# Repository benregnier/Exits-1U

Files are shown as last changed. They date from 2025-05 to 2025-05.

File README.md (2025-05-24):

# Exits
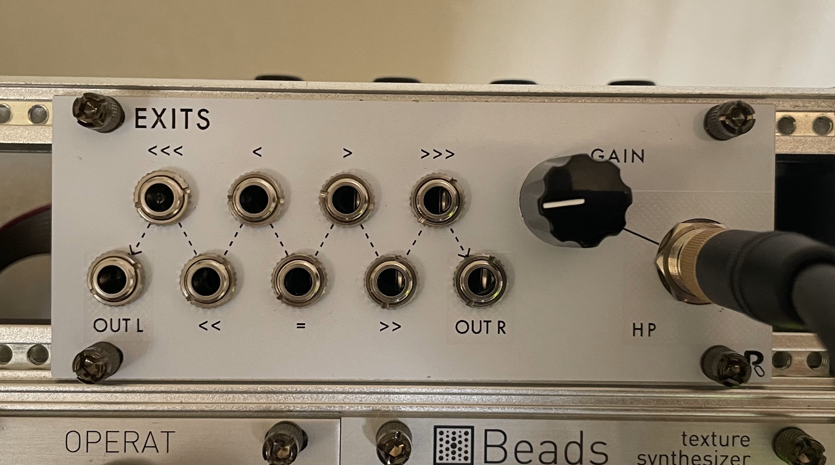
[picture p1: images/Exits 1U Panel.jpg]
exits


4hp DIY eurorack line and headphone output module based on [Exits](https://github.com/ramphands/Exits) which is in part based on [Nearness](https://github.com/sarnesjo/nearness) and [Forestcaver headphone amp](https://github.com/forestcaver/Analog-Voice/tree/master/AJH_Headphone_Amp) designs. 

The Nearness section is a "minimal panning mixer for the Eurorack modular synthesizer system. Seven inputs, two outputs. The closer an input is to an output, the greater its influence on it."  

This design makes the following changes:
- Changed to a 1U format
- Reestablishes front panel L and R outputs
- In lieu of a stereo 1/4 main out, has a six-pin connector that is compatible with Intellijel cases.
- NE5532 in lieu of NJM4556 for the headphone portion

## Schematic and PCBs

The [kicad](Kicad) directory contains the schematic and PCB layout as a KiCad 6 project.

## Panel

Available in the [panel](Panel) directory as a PDF and an SVG vector file as well as PCB design and gerbers.

## Intellijel Output Pinout

This module has a six pin connector on the back meant to be compatible with outputs on Intellijel and Befaco cases. Pinouts match per the diagram below. Outputs are not balanced.  Note that if you want to mount this module on the far right hand side of the case both the output and power ribbon cables need to be low-profile.  

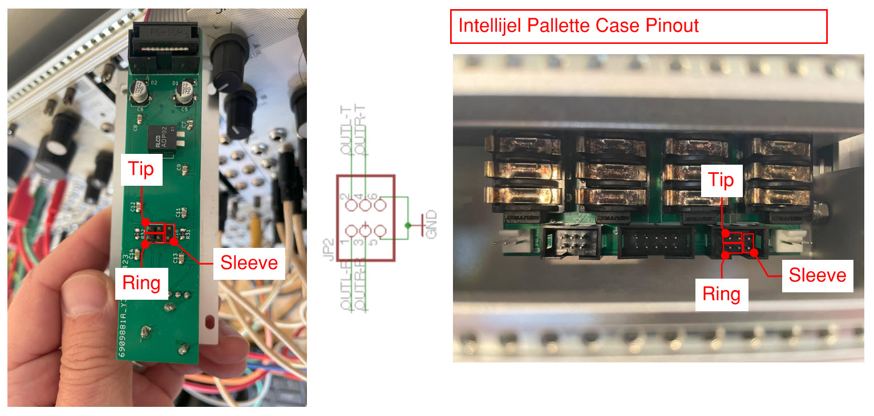
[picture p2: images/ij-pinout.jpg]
pinout


## License

[CC BY-SA 4.0](http://creativecommons.org/licenses/by-sa/4.0/)

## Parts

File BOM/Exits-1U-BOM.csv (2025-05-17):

Id | Designator | Footprint | Quantity | Designation | Supplier and ref
1 | IC2,IC1 | SOIC-8_3.9x4.9mm_P1.27mm | 2 | NE5532
2 | J2,J13,J1,J15,J6,J3,J4,J5,J7 | PJ301M12 | 9 | PJ301M12
3 | U4,U3 | SOIC-8_3.9x4.9mm_P1.27mm | 2 | LME49720
4 | R17,R27,R28,R19,R15,R16,R20,R21,R18,R22,R1,R14 | R_0805_2012Metric_Pad1.20x1.40mm_HandSolder | 12 | 100k
5 | RV1 | Potentiometer_Alpha_RD902F-40-00D_Dual_Vertical | 1 | 50k A
6 | C4,C3 | C_0805_2012Metric_Pad1.18x1.45mm_HandSolder | 2 | 22p
7 | R23,R25,R26,R24 | R_0805_2012Metric_Pad1.20x1.40mm_HandSolder | 4 | 1
8 | J14 | CUI_SJ-63083A | 1 | SJ-63083A
9 | R30,R29,R31,R32 | R_0805_2012Metric_Pad1.20x1.40mm_HandSolder | 4 | 1k
10 | C2,C1,C8,C14,C13,C9,C12,C10,C7,C11 | C_0805_2012Metric_Pad1.18x1.45mm_HandSolder | 10 | 100n
11 | J8 | PinHeader_1x04_P2.54mm_Vertical | 1 | Conn_01x04_Male
12 | J11 | PinHeader_1x06_P2.54mm_Vertical | 1 | Conn_01x06_Male
13 | C6,C5 | C_Elec_5x5.8 | 2 | 22u
14 | R9,R6 | R_0805_2012Metric_Pad1.20x1.40mm_HandSolder | 2 | 215k
15 | J10 | PinSocket_1x06_P2.54mm_Vertical | 1 | Conn_01x06_Female
16 | J16 | PinHeader_2x03_P2.54mm_Vertical | 1 | Conn_02x03_Odd_Even
17 | J12 | IDC-Header_2x05_P2.54mm_Vertical | 1 | Euro power header
18 | R8,R7 | R_0805_2012Metric_Pad1.20x1.40mm_HandSolder | 2 | 140k
19 | S1 | ADP0204 | 1 | ADP0204
20 | R10,R5 | R_0805_2012Metric_Pad1.20x1.40mm_HandSolder | 2 | 113k
21 | D1,D2 | D_SOD-123 | 2 | 1N5819HW
22 | J9 | PinSocket_1x04_P2.54mm_Vertical | 1 | Conn_01x04_Female
23 | R11,R4 | R_0805_2012Metric_Pad1.20x1.40mm_HandSolder | 2 | 442k
24 | R13,R2 | R_0805_2012Metric_Pad1.20x1.40mm_HandSolder | 2 | 1M69
25 | R12,R3 | R_0805_2012Metric_Pad1.20x1.40mm_HandSolder | 2 | 102k

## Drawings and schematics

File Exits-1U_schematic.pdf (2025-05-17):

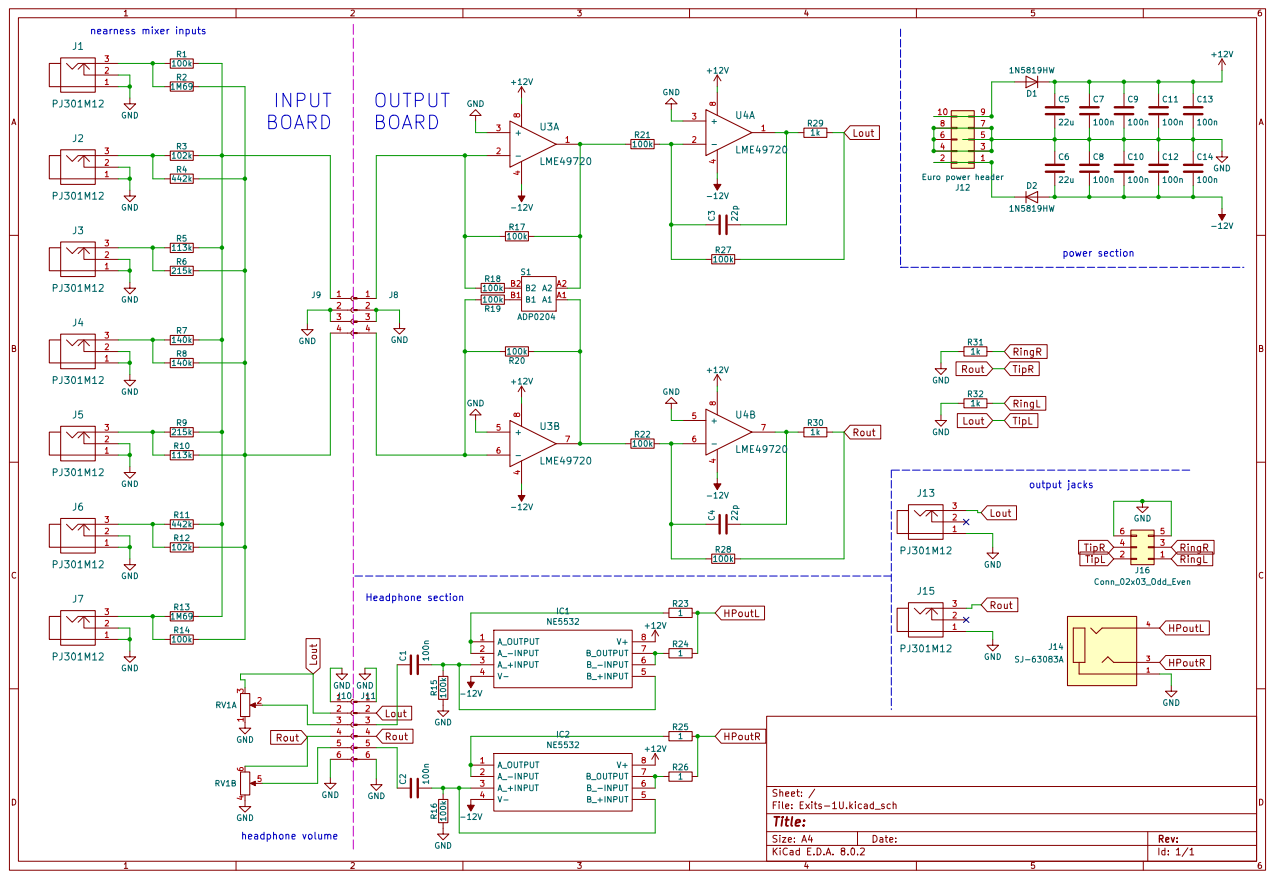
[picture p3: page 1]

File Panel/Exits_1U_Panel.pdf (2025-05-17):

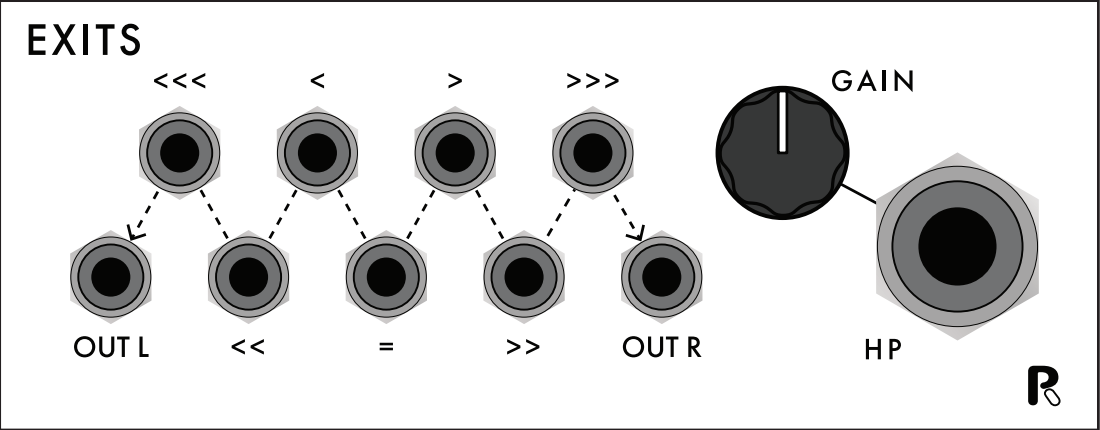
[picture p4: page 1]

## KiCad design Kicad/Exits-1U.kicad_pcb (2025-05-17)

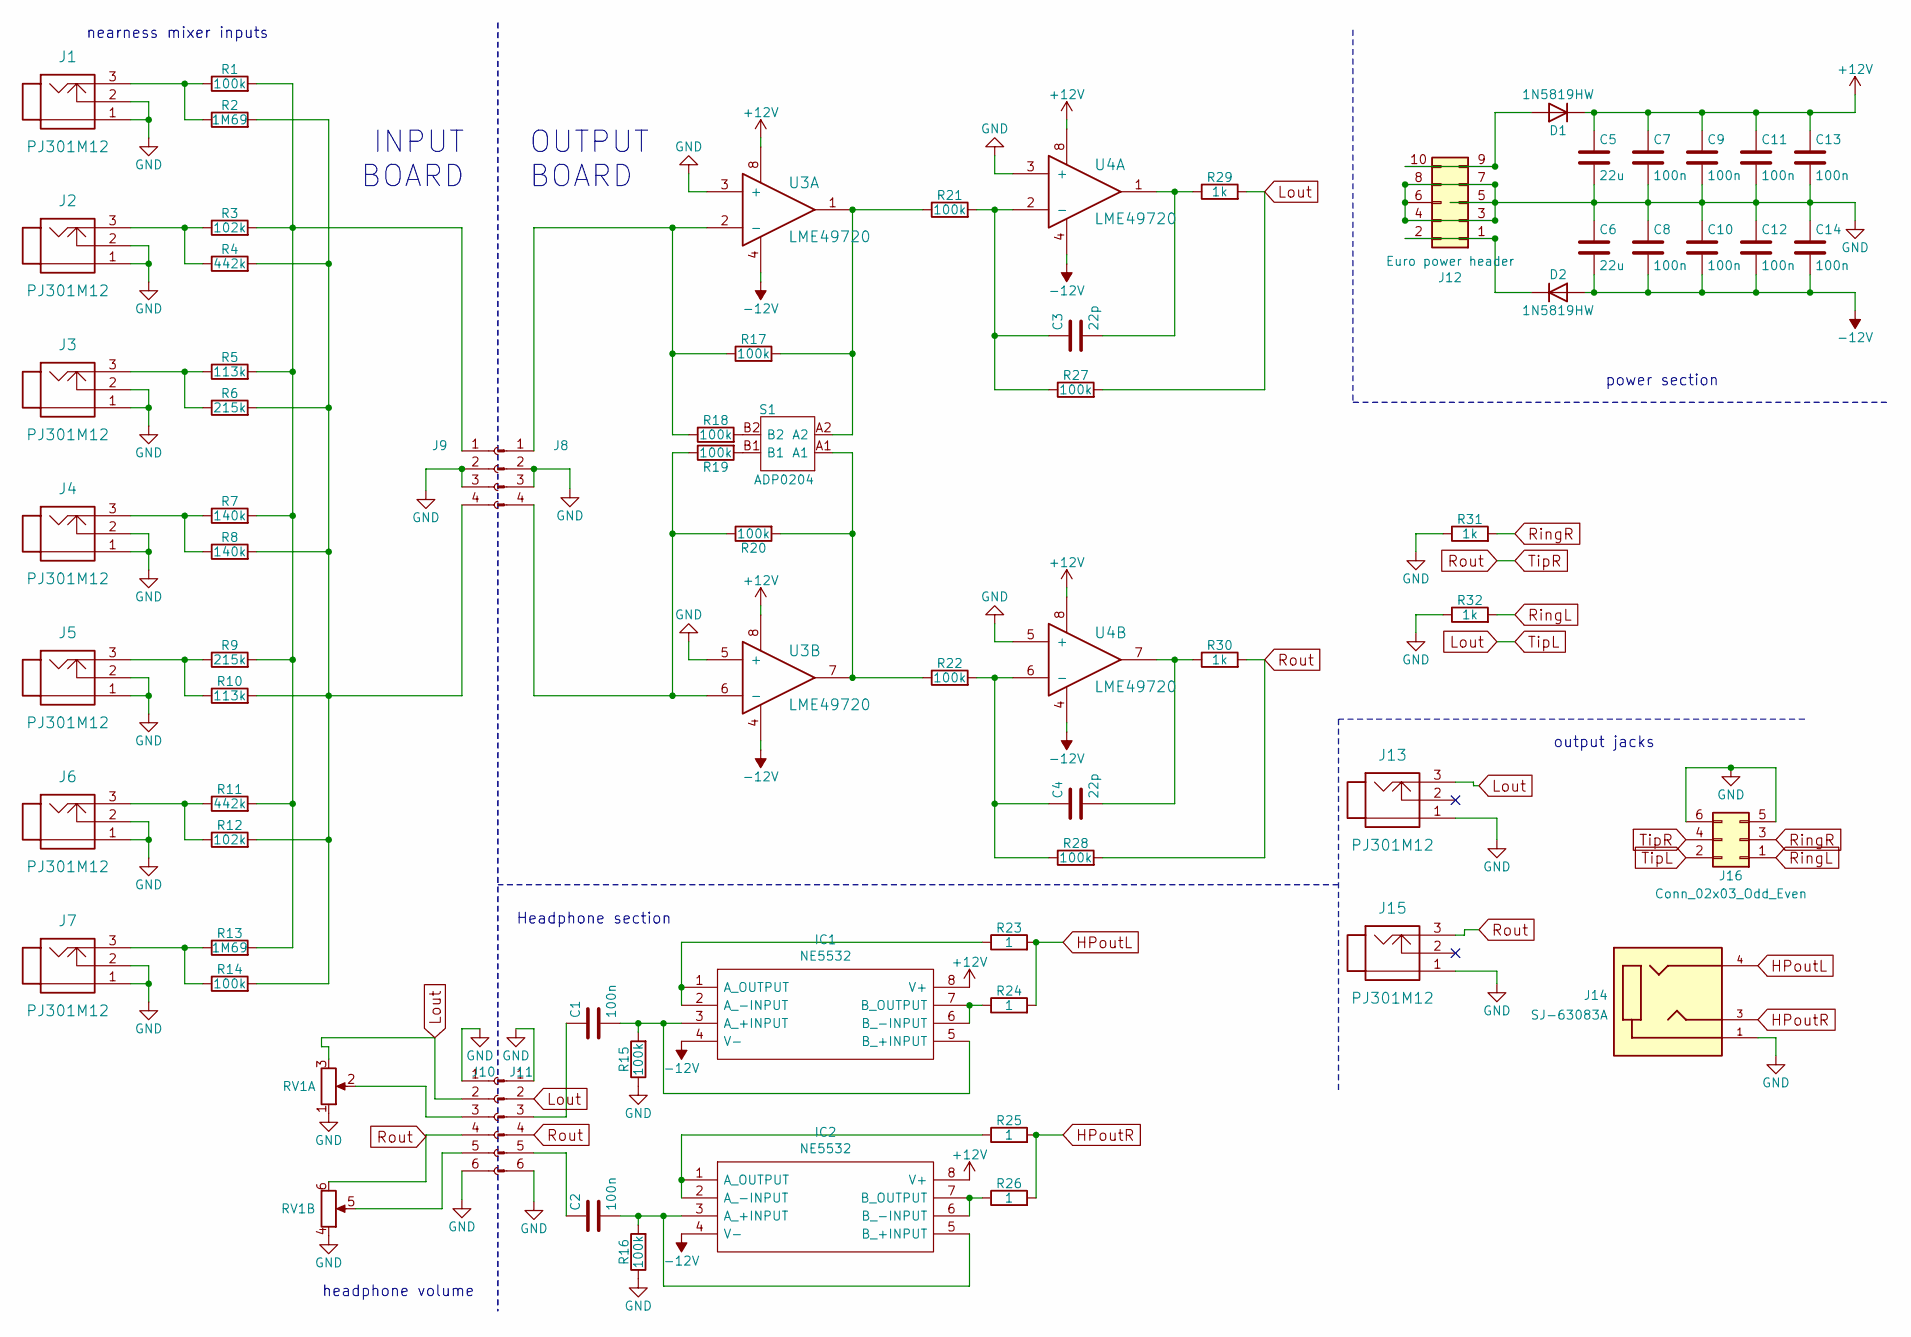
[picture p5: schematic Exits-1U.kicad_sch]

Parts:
C1, C2, C7, C8, C9, C10, C11, C12, C13, C14: 100n; C_0805_2012Metric_Pad1.18x1.45mm_HandSolder
C3, C4: 22p; C_0805_2012Metric_Pad1.18x1.45mm_HandSolder
C5, C6: 22u; C_Elec_5x5.8
D1, D2: 1N5819HW; D_SOD-123
IC1: NE5532; SOIC-8_3.9x4.9mm_P1.27mm; Manufacturer_Part_Number NE5532
IC2: NE5532; SOIC-8_3.9x4.9mm_P1.27mm; Mouser Part Number 513-NJM4556AV-TE1
J1, J2, J3, J4, J5, J6, J7, J13, J15: PJ301M12
J8: Conn_01x04_Male; PinHeader_1x04_P2.54mm_Vertical
J9: Conn_01x04_Female; PinSocket_1x04_P2.54mm_Vertical
J10: Conn_01x06_Female; PinSocket_1x06_P2.54mm_Vertical
J11: Conn_01x06_Male; PinHeader_1x06_P2.54mm_Vertical
J12: Euro power header; IDC-Header_2x05_P2.54mm_Vertical
J14: SJ-63083A; CUI_SJ-63083A; PARTREV 1.0
J16: Conn_02x03_Odd_Even; PinHeader_2x03_P2.54mm_Vertical
R1, R14, R15, R16, R17, R18, R19, R20, R21, R22, R27, R28: 100k; R_0805_2012Metric_Pad1.20x1.40mm_HandSolder
R2, R13: 1M69; R_0805_2012Metric_Pad1.20x1.40mm_HandSolder
R3, R12: 102k; R_0805_2012Metric_Pad1.20x1.40mm_HandSolder
R4, R11: 442k; R_0805_2012Metric_Pad1.20x1.40mm_HandSolder
R5, R10: 113k; R_0805_2012Metric_Pad1.20x1.40mm_HandSolder
R6, R9: 215k; R_0805_2012Metric_Pad1.20x1.40mm_HandSolder
R7, R8: 140k; R_0805_2012Metric_Pad1.20x1.40mm_HandSolder
R23, R24, R25, R26: 1; R_0805_2012Metric_Pad1.20x1.40mm_HandSolder
R29, R30, R31, R32: 1k; R_0805_2012Metric_Pad1.20x1.40mm_HandSolder
RV1: 50k A; Potentiometer_Alpha_RD902F-40-00D_Dual_Vertical
S1: ADP0204; Mouser Part Number 506-ADP0204
U3, U4: LME49720; SOIC-8_3.9x4.9mm_P1.27mm

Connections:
+12V: C5.1, C7.1, C9.1, C11.1, C13.1, D1.1 (K), IC1.8 (V+), IC2.8 (V+), U3.8, U4.8
-12V: C6.2, C8.2, C10.2, C12.2, C14.2, D2.2 (A), IC1.4 (V-), IC2.4 (V-), U3.4, U4.4
GND: C5.2, C6.1, C7.2, C8.1, C9.2, C10.1, C11.2, C12.1, C13.2, C14.1, J1.1, J1.2, J2.1, J2.2, J3.1, J3.2, J4.1, J4.2, J5.1, J5.2, J6.1, J6.2, J7.1, J7.2, J8.2, J8.3, J9.2, J9.3, J10.1, J10.6, J11.1, J11.6, J12.3, J12.4, J12.5, J12.6, J12.7, J12.8, J13.1, J14.1, J15.1, J16.5, J16.6, R15.1, R16.1, R31.1, R32.1, RV1.1, RV1.4, U3.3 (+), U3.5 (+), U4.3 (+), U4.5 (+)
HPoutL: J14.4, R23.2, R24.2
HPoutR: J14.3, R25.2, R26.2
Lout: J10.2, J11.2, J13.3, J16.2, R27.2, R29.2, RV1.3
unnamed: C3.2, R29.1, U4.1
unnamed: C4.2, R30.1, U4.7
unnamed: D1.2 (A), J12.9, J12.10
unnamed: D2.1 (K), J12.1, J12.2
unnamed: C1.2, IC1.3 (A_+INPUT), IC1.5 (B_+INPUT), R15.2
unnamed: IC1.1 (A_OUTPUT), IC1.2 (A_-INPUT), R23.1
unnamed: IC1.6 (B_-INPUT), IC1.7 (B_OUTPUT), R24.1
unnamed: C2.2, IC2.3 (A_+INPUT), IC2.5 (B_+INPUT), R16.2
unnamed: IC2.1 (A_OUTPUT), IC2.2 (A_-INPUT), R25.1
unnamed: IC2.6 (B_-INPUT), IC2.7 (B_OUTPUT), R26.1
unnamed: J1.3, R1.1, R2.1
unnamed: J2.3, R3.1, R4.1
unnamed: J3.3, R5.1, R6.1
unnamed: J4.3, R7.1, R8.1
unnamed: J5.3, R9.1, R10.1
unnamed: J6.3, R11.1, R12.1
unnamed: J7.3, R13.1, R14.1
unnamed: J8.1, R17.1, R18.1, U3.2 (-)
unnamed: J8.4, R19.1, R20.1, U3.6 (-)
unnamed: J9.1, R1.2, R3.2, R5.2, R7.2, R9.2, R11.2, R13.2
unnamed: J9.4, R2.2, R4.2, R6.2, R8.2, R10.2, R12.2, R14.2
unnamed: J10.3, RV1.2
unnamed: J10.5, RV1.5
unnamed: C1.1, J11.3
unnamed: C2.1, J11.5
unnamed: R17.2, R21.1, S1.A2, U3.1
unnamed: R18.2, S1.B2
unnamed: R19.2, S1.B1
unnamed: R20.2, R22.1, S1.A1, U3.7
unnamed: C3.1, R21.2, R27.1, U4.2 (-)
unnamed: C4.1, R22.2, R28.1, U4.6 (-)
RingL: J16.1, R32.2
RingR: J16.3, R31.2
Rout: J10.4, J11.4, J15.3, J16.4, R28.2, R30.2, RV1.6

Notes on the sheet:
headphone volume
INPUT BOARD
Headphone section
OUTPUT BOARD
output jacks
nearness mixer inputs
power section

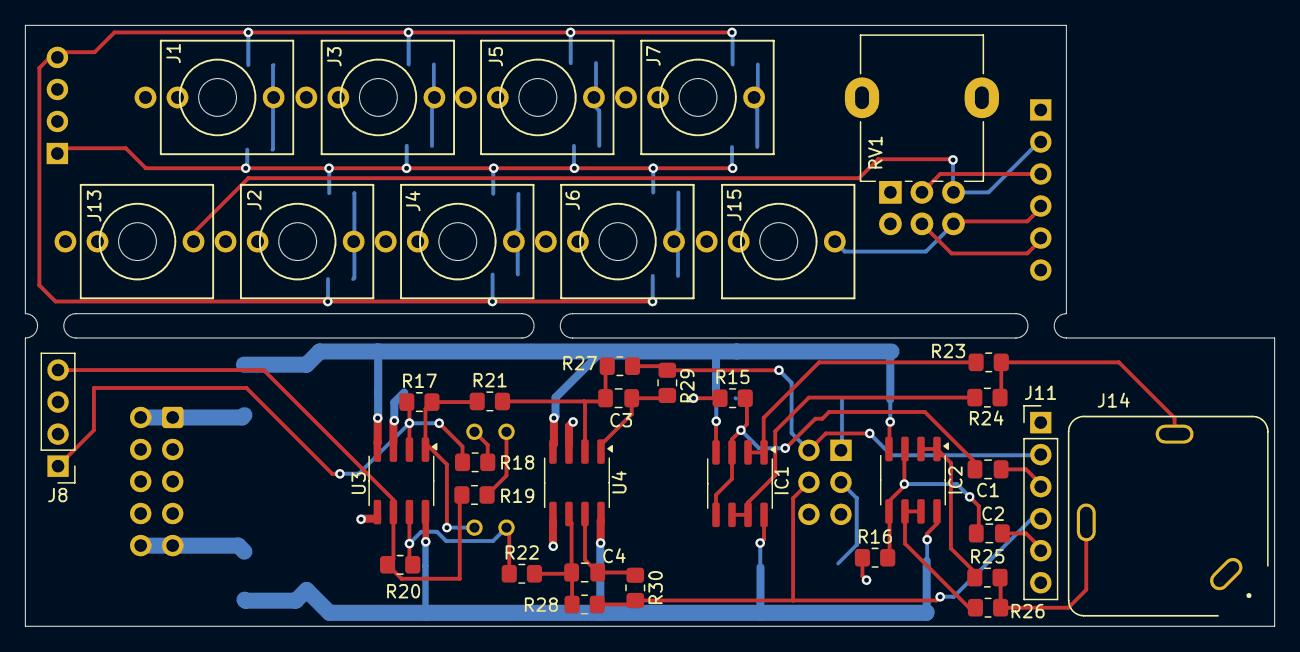
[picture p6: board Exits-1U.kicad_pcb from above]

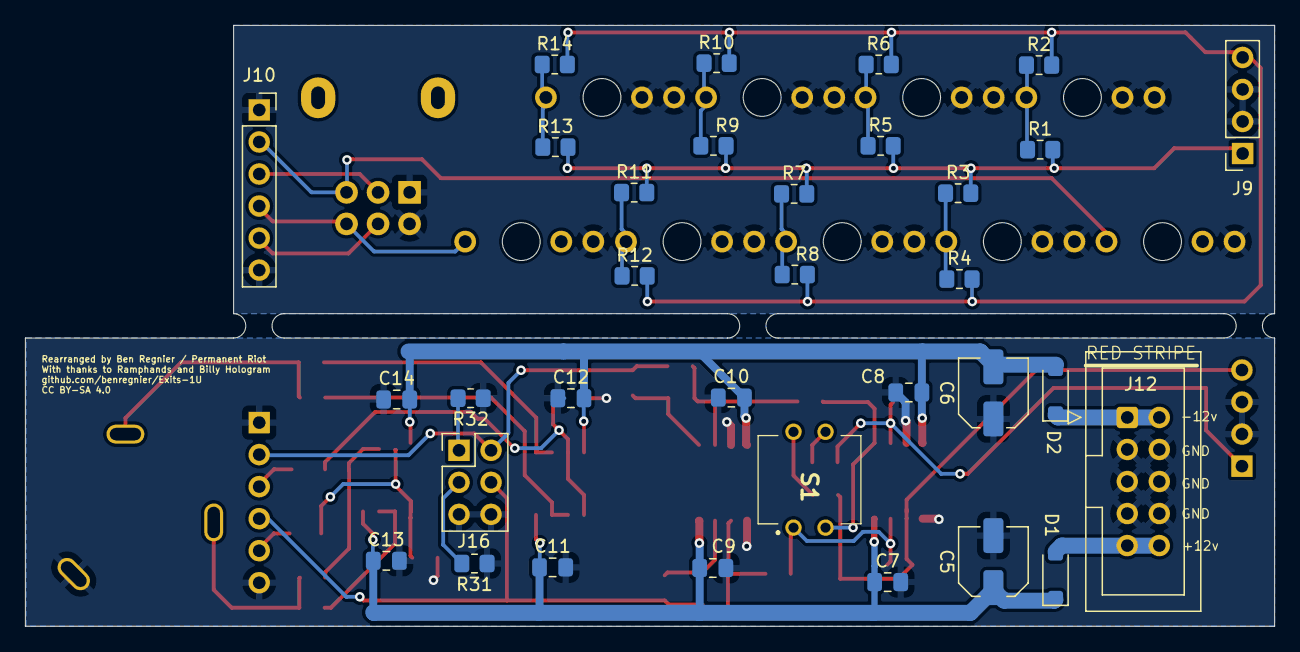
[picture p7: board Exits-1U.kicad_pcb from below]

Board: 2 copper layers, 99.1 x 47.7 mm, 70 parts (33 on the bottom side), 40 nets.

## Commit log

2025-05-17 Update and rename Panel/Exits-1U-panel-B_Cu.gbr to Panel/Gerbers/Exits-1U-panel-B_Cu.gbr
    [Exits-1U-panel-B_Cu.gbr]
2025-05-17 Update and rename Panel/Exits-1U-panel-B_Mask.gbr to Panel/Gerbers/Exits-1U-panel-B_Mask.gbr
    [Exits-1U-panel-B_Mask.gbr]
2025-05-17 Update and rename Panel/Exits-1U-panel-B_Silkscreen.gbr to Panel/Gerbers/Exits-1U-panel-B_Silkscreen.gbr
    [Exits-1U-panel-B_Silkscreen.gbr]
2025-05-17 Update and rename Panel/Exits-1U-panel-Edge_Cuts.gbr to Panel/Gerbers/Exits-1U-panel-Edge_Cuts.gbr
    [Exits-1U-panel-Edge_Cuts.gbr]
2025-05-17 Update and rename Panel/Exits-1U-panel-F_Cu.gbr to Panel/Gerbers/Exits-1U-panel-F_Cu.gbr
    [Exits-1U-panel-F_Cu.gbr]
2025-05-17 Update and rename Panel/Exits-1U-panel-F_Mask.gbr to Panel/Gerbers/Exits-1U-panel-F_Mask.gbr
    [Exits-1U-panel-F_Mask.gbr]
2025-05-17 Update and rename Panel/Exits-1U-panel-F_Silkscreen.gbr to Panel/Gerbers/Exits-1U-panel-F_Silkscreen.gbr
    [Exits-1U-panel-F_Silkscreen.gbr]
